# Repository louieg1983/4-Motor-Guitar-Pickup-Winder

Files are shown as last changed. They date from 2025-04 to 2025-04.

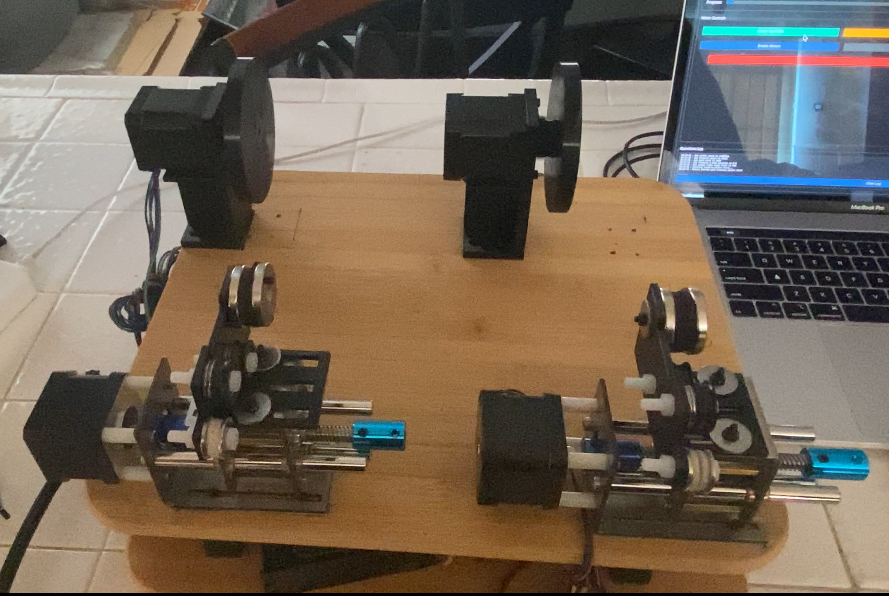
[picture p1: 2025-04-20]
Winder_Setup.jpg

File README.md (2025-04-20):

# 4-Motor-Guitar-Pickup-Winder

This project uses 4 stepper motors to wind guitar pickups. 

How it works:

There are two motors that will turn the bobbins and there are two motors that serve as traverse motors. The code has Winder Motor 2 and Traverse Motor 2 mirror the main motors. You can edit the code to control the motors individually if you would like but my goal was to wind a set of humbuckers in one shot to save time and resources. 

All motors are NEMA 17 stepper Motors. They are being driven by TB6600 Stepper Motor Drivers. The Winder Motors are set to 32 micro steps while the Traverse Motors are set to 16 micro steps. All are being powered by a 36V 10A Switch Power Supply. So far there have been no issues with this configuration. 

The TB6600 motors are then connected to the pins on the ESP32 board. You can use an Arduino board if you would like. You will just need to edit the code accroding to the pins that you are using. 

I built a wire feeder using Tinkercad. I can provide that STL file as well. You can also design your own if you would like. So far, no issues at all. Though I would like to come up with a more elegant solution. At the moment, I am using two rollers, custom made tensioner (two metal washers with felt washers, nylon screws and nuts to hold everything to the wire feeder plate, and two Neodymium magnets with felt pads. The theory or thought process was to use the washers with felt to keep the wire from bouncing all over the place and have some tension and then have the magnets keep the constant tension as the wire is feed to the bobbin. 

Amazon links for the parts used:

4 - https://www.amazon.com/dp/B07PQ5KNKR?ref=ppx_yo2ov_dt_b_fed_asin_title

2 - https://www.amazon.com/dp/B09KRJDRVH?ref=ppx_yo2ov_dt_b_fed_asin_title

2- https://www.amazon.com/dp/B00PNEQKC0?ref=ppx_yo2ov_dt_b_fed_asin_title

1 - https://www.amazon.com/dp/B01EV70C78?ref=ppx_yo2ov_dt_b_fed_asin_title

1 - https://www.amazon.com/dp/B08H292YZV?ref=ppx_yo2ov_dt_b_fed_asin_title

1 - https://www.amazon.com/dp/B097R2JMJT?ref=ppx_yo2ov_dt_b_fed_asin_title&th=1

1- https://www.amazon.com/dp/B0CLK7J4NB?ref=ppx_yo2ov_dt_b_fed_asin_title&th=1

1- https://www.amazon.com/dp/B0B82BBKCY?ref=ppx_yo2ov_dt_b_fed_asin_title&th=1

1 - https://www.amazon.com/dp/B082TQ11P2?ref=ppx_yo2ov_dt_b_fed_asin_title&th=1

1 - https://www.amazon.com/dp/B01NBE2XIR?ref_=ppx_hzsearch_conn_dt_b_fed_asin_title_1

Total cost is below $200. Great deal considering CNC Guitar Pickup Winders are about 6 to 7 times more. I could be wrong, I no math goods. 

I used the videos as well as resrouces from other builders. I drew a lot of inspiration from all these resources. Lots of great stuff out there. Hopefully you find something that you click with and you can use this design to build your own design. If you do, please do me the honors and share your work of art with me. I would love to see if this helps!

Resources/Inspirations/3D Parts

https://github.com/sandy9159/DIY-Arduino-based-Guitar-Pickup-Coil-Winder

https://github.com/fps/OPWF

https://github.com/speccyfan/wm/blob/master/wm1.1/stl/bracket-right.stl

https://www.youtube.com/watch?v=pJiwjPVOXLA

https://www.youtube.com/watch?v=IrS8BBjuDdw

https://www.youtube.com/watch?v=xya4ipu7bTk

https://www.youtube.com/watch?v=YcfYJsYc00k

https://www.youtube.com/watch?v=phCA-h2uJGQ&t=526s

https://www.youtube.com/shorts/mcej-a_-2Q8

https://www.youtube.com/watch?v=2DeUdFgyJEU

https://www.youtube.com/watch?v=DuSMk63nonc&t=84s

Also, if you do not have a 3D printer you may want to invest in a cheap one just to print out the parts otherwise you will need to buy something comparable or you can enlist the services of someone with a 3D printer. 

I hope this helps! And HAVE FUN!

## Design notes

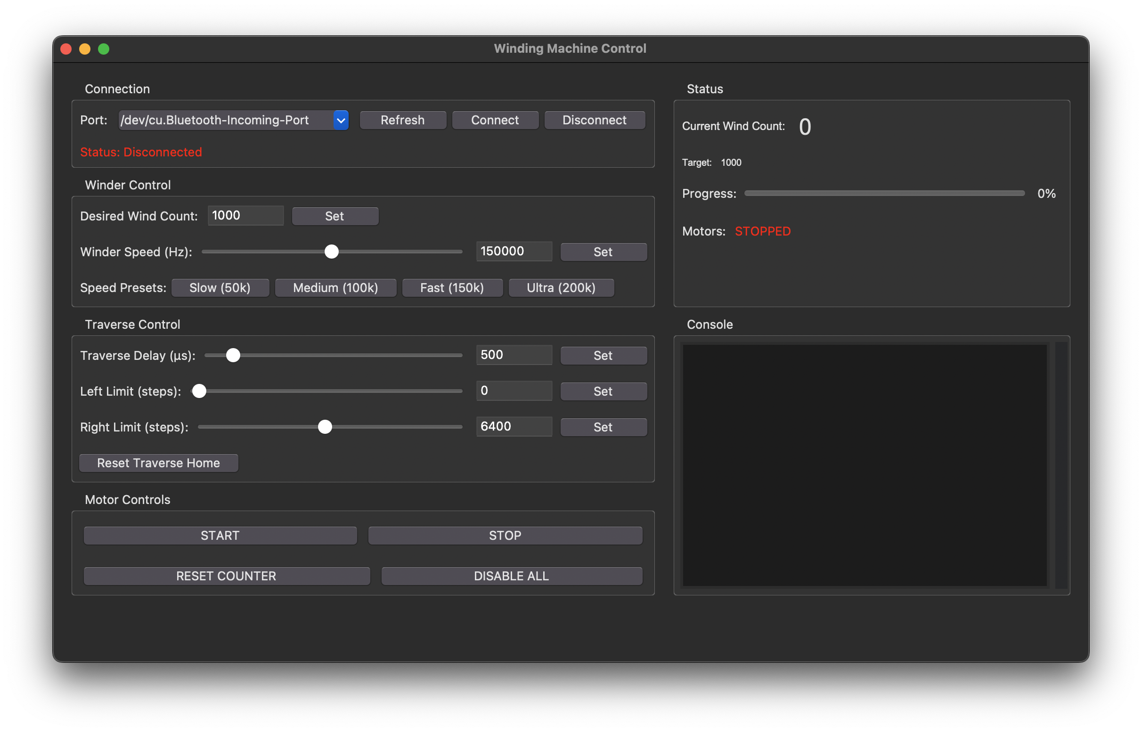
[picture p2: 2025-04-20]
Python_GUI.png

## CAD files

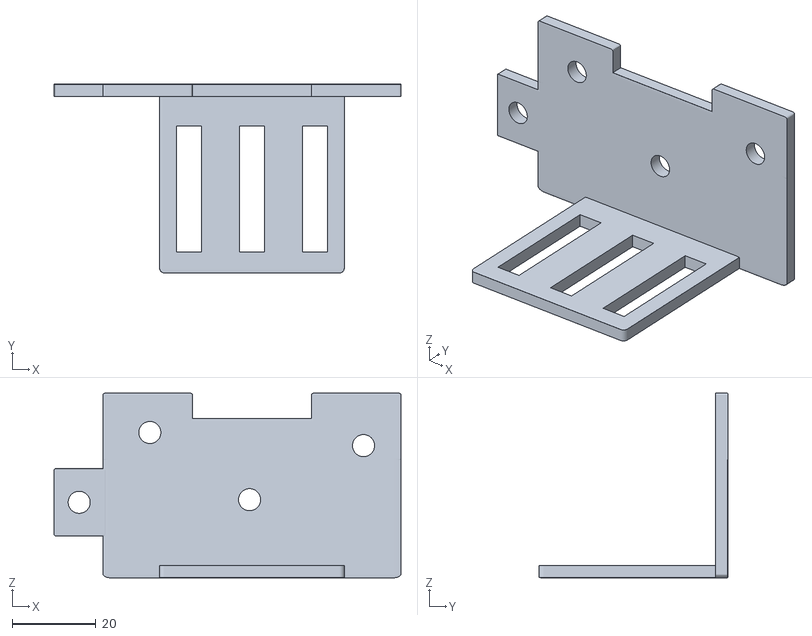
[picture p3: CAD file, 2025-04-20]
WIRE_FEEDER_TRAVERSE_PLATE.stl
82.7 x 45.0 x 44.0

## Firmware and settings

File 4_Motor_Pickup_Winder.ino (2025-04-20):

#include <FastAccelStepper.h>

//-------------------- Pin Definitions --------------------
// Winder Motor Pins
#define WINDER_DIR_PIN      26    // Direction pin for Winder Motor
#define WINDER_STEP_PIN     27    // Step pulse pin for Winder Motor
#define WINDER_ENABLE_PIN   32    // Enable pin for Winder Motor (LOW enables)

// Traverse Motor Pins
#define TRAVERSE_DIR_PIN    13    // Direction pin for Traverse Motor
#define TRAVERSE_STEP_PIN   12    // Step pulse pin for Traverse Motor
#define TRAVERSE_ENABLE_PIN 33    // Enable pin for Traverse Motor (LOW enables)

// Hall Sensor Pin
#define HALL_SENSOR_PIN     34

// Additional Winder Motor Pins
#define WINDER2_DIR_PIN     25    // Direction pin for 2nd Winder Motor
#define WINDER2_STEP_PIN    14    // Step pulse pin for 2nd Winder Motor
#define WINDER2_ENABLE_PIN  23    // Enable pin for 2nd Winder Motor (LOW enables)

// Additional Traverse Motor Pins
#define TRAVERSE2_DIR_PIN   4     // Direction pin for Traverse Motor 2
#define TRAVERSE2_STEP_PIN  2     // Step pulse pin for Traverse Motor 2
#define TRAVERSE2_ENABLE_PIN 15   // Enable pin for Traverse Motor 2 (LOW enables)

//-------------------- Global Objects --------------------
FastAccelStepperEngine engine = FastAccelStepperEngine();
FastAccelStepper *winderStepper = NULL;
FastAccelStepper *winder2Stepper = NULL;
FastAccelStepper *traverseStepper = NULL;
FastAccelStepper *traverse2Stepper = NULL;

//-------------------- Global Variables --------------------
// Control flags
bool motorsRunning = false;  

// Winder Motor Variables
volatile long windCount = 0;      // Incremented via ISR on hall sensor
int desiredWindCount = 1000;      // Target wind count
long winderSpeed = 150000;        // Default winder speed (Hz)
long winderAcceleration = 20000;  // Winder acceleration
const int slowdownWinds = 111;    // Slowdown threshold

// Traverse Motor Variables
const int STEPS_PER_REVOLUTION = 3200;  // 3200 microsteps per revolution
int traverseStepDelay = 500;      // Delay per half-step (µs)
int leftSweepLimit = 0;           // Left sweep limit in steps
int rightSweepLimit = 6400;       // Right sweep limit in steps
bool traverseMovingRight = true;  // Traverse direction flag
int currentTraverseStep = 0;      // Current traverse position in steps
int currentTraverse2Step = 0;     // Current traverse2 position in steps

//-------------------- Status Timer Variables --------------------
unsigned long lastStatusPrintTime = 0;
const unsigned long statusPrintInterval = 1000; // 1 second

//-------------------- Function Prototypes --------------------
void processCommand(String command);
void updateWinderSpeed();
void moveTraverseToPosition(int targetSteps);
void moveTraverse2ToPosition(int targetSteps);
void startMotors();
void stopMotors();
void countWinds();
void pulseTraverseStep(int pin, int delay_us);
void controlBothTraverseMotors(int stepDelay, int leftLimit, int rightLimit);
void disableAllMotors();

//-------------------- Helper Function for Step Pulses --------------------
void pulseTraverseStep(int pin, int delay_us) {
  digitalWrite(pin, HIGH);
  delayMicroseconds(10); // Ensure minimum pulse width
  digitalWrite(pin, LOW);
  delayMicroseconds(delay_us - 10 > 0 ? delay_us - 10 : 1); // Maintain timing
}

//-------------------- Control Both Traverse Motors --------------------
void controlBothTraverseMotors(int stepDelay, int leftLimit, int rightLimit) {
  if (traverseMovingRight) {
    // Both motors moving right (increasing position)
    if (currentTraverseStep >= rightLimit) {
      // Reached right limit, change direction for both motors
      traverseMovingRight = false;
      Serial.println("Traverse: Changing direction to LEFT");
    } else {
      // Continue moving right for both motors
      // Traverse 1
      digitalWrite(TRAVERSE_DIR_PIN, HIGH); // Direction for RIGHT movement
      pulseTraverseStep(TRAVERSE_STEP_PIN, stepDelay);
      currentTraverseStep++; // Update position
      
      // Traverse 2 - SAME direction
      digitalWrite(TRAVERSE2_DIR_PIN, HIGH); // Direction for RIGHT movement
      pulseTraverseStep(TRAVERSE2_STEP_PIN, stepDelay);
      currentTraverse2Step++; // Update position
    }
  } else {
    // Both motors moving left (decreasing position)
    if (currentTraverseStep <= leftLimit) {
      // Reached left limit, change direction for both motors
      traverseMovingRight = true;
      Serial.println("Traverse: Changing direction to RIGHT");
    } else {
      // Continue moving left for both motors
      // Traverse 1
      digitalWrite(TRAVERSE_DIR_PIN, LOW); // Direction for LEFT movement
      pulseTraverseStep(TRAVERSE_STEP_PIN, stepDelay);
      currentTraverseStep--; // Update position
      
      // Traverse 2 - SAME direction
      digitalWrite(TRAVERSE2_DIR_PIN, LOW); // Direction for LEFT movement
      pulseTraverseStep(TRAVERSE2_STEP_PIN, stepDelay);
      currentTraverse2Step--; // Update position
    }
  }
}

//-------------------- Process Serial Commands --------------------
void processCommand(String command) {
  if (command == "S") {
    startMotors();
  }
  else if (command == "T") {
    stopMotors();
  }
  else if (command == "R") {
    windCount = 0;
    Serial.println("Wind count reset to 0.");
    Serial.print("Current wind count: ");
    Serial.println(windCount);
  
    // Monitor the Hall sensor status
    Serial.print("Hall sensor current state: ");
    Serial.println(digitalRead(HALL_SENSOR_PIN) == HIGH ? "HIGH" : "LOW");
  }
  else if (command.startsWith("N")) {
    int newWindCount = command.substring(1).toInt();
    if (newWindCount > 0) {
      desiredWindCount = newWindCount;
      Serial.print("Desired wind count set to ");
      Serial.println(desiredWindCount);
    }
  }
  else if (command.startsWith("w_speed:")) {
    long newSpeed = command.substring(8).toInt();
    if (newSpeed > 0) {
      winderSpeed = newSpeed;
      if (winderStepper && motorsRunning) {
        winderStepper->setSpeedInHz(winderSpeed);
      }
      if (winder2Stepper && motorsRunning) {
        winder2Stepper->setSpeedInHz(winderSpeed);
      }
      Serial.print("Winder speed set to ");
      Serial.print(winderSpeed);
      Serial.println(" Hz");
    }
  }
  else if (command.startsWith("t_speed:")) {
    int newDelay = command.substring(8).toInt();
    if (newDelay > 0) {
      traverseStepDelay = newDelay;
      Serial.print("Traverse step delay set to ");
      Serial.print(traverseStepDelay);
      Serial.println(" microseconds");
    }
  }
  else if (command.startsWith("t_leftlimit:")) {
    int newLimit = command.substring(12).toInt();
    leftSweepLimit = newLimit;
    Serial.print("Left sweep limit set to ");
    Serial.println(leftSweepLimit);
  }
  else if (command.startsWith("t_rightlimit:")) {
    int newLimit = command.substring(13).toInt();
    if (newLimit >= 0 && newLimit <= 12800) {  // Allow up to 4 full revolutions
      rightSweepLimit = newLimit;
      Serial.print("Right sweep limit set to: ");
      Serial.println(rightSweepLimit);
    } else {
      Serial.println("Error: Right limit must be between 0 and 12800");
    }
  }
  else if (command == "t_home") {
    currentTraverseStep = 0;
    Serial.println("Traverse position reset to home (0)");
  }
  else if (command == "disable_all_motors") {
    disableAllMotors();
  }
  else {
    Serial.print("Unknown command: ");
    Serial.println(command);
  }
}

//-------------------- Start Motors Function --------------------
void startMotors() {
  if (!motorsRunning) {
    // Enable traverse motors first
    digitalWrite(TRAVERSE_ENABLE_PIN, LOW);
    digitalWrite(TRAVERSE2_ENABLE_PIN, LOW);
    
    // Initialize traverse direction flags
    traverseMovingRight = true;
    
    // Send a burst of steps to get the traverse motors moving
    Serial.println("Starting traverse motors first...");
    for (int i = 0; i < 50; i++) {
      digitalWrite(TRAVERSE_DIR_PIN, HIGH);
      digitalWrite(TRAVERSE2_DIR_PIN, HIGH);
      
      pulseTraverseStep(TRAVERSE_STEP_PIN, 300); 
      pulseTraverseStep(TRAVERSE2_STEP_PIN, 300);
      delay(5);
    }
    
    // Add a delay before starting winder motors
    delay(1000);
    
    Serial.println("Traverse motors running, now starting winder motors...");
    
    // Initialize the winder motors
    if (winderStepper) {
      winderStepper->stopMove();
      winderStepper->forceStopAndNewPosition(0);
    }
    
    if (winder2Stepper) {
      winder2Stepper->stopMove();
      winder2Stepper->forceStopAndNewPosition(0);
    }
    
    // Enable Winder Motors
    digitalWrite(WINDER_ENABLE_PIN, LOW);
    digitalWrite(WINDER2_ENABLE_PIN, LOW);
    
    // Configure and start the Winder Motors rotation
    if (winderStepper) {
      winderStepper->setSpeedInHz(winderSpeed);
      winderStepper->setAcceleration(winderAcceleration);
      winderStepper->runForward();
    }
    
    if (winder2Stepper) {
      winder2Stepper->setSpeedInHz(winderSpeed);
      winder2Stepper->setAcceleration(winderAcceleration);
      winder2Stepper->runForward();
    }
    
    // Set flag
    motorsRunning = true;
    
    Serial.println("All motors running");
  }
}

//-------------------- Disable All Motors Function --------------------
void disableAllMotors() {
  // First stop any stepper movement
  if (winderStepper) {
    winderStepper->stopMove();
    winderStepper->forceStopAndNewPosition(0);
    winderStepper->disableOutputs();
  }
  if (winder2Stepper) {
    winder2Stepper->stopMove();
    winder2Stepper->forceStopAndNewPosition(0);
    winder2Stepper->disableOutputs();
  }
  
  // Disable all motor outputs
  digitalWrite(WINDER_ENABLE_PIN, HIGH);
  digitalWrite(WINDER2_ENABLE_PIN, HIGH);
  digitalWrite(TRAVERSE_ENABLE_PIN, HIGH);
  digitalWrite(TRAVERSE2_ENABLE_PIN, HIGH);
  
  // Update state flag
  motorsRunning = false;
  
  Serial.println("All motors disabled.");
}

//-------------------- Stop Motors Function --------------------
void stopMotors() {
  if (motorsRunning) {
    // Stop the winder stepper motors
    if (winderStepper) {
      winderStepper->stopMove();
      winderStepper->forceStopAndNewPosition(0);
    }
    if (winder2Stepper) {
      winder2Stepper->stopMove();
      winder2Stepper->forceStopAndNewPosition(0);
    }
    
    // Disable all motors
    digitalWrite(WINDER_ENABLE_PIN, HIGH);
    digitalWrite(WINDER2_ENABLE_PIN, HIGH);
    digitalWrite(TRAVERSE_ENABLE_PIN, HIGH);
    digitalWrite(TRAVERSE2_ENABLE_PIN, HIGH);
    
    // Update motor running flag
    motorsRunning = false;
    
    Serial.println("All motors stopped and disabled.");
  }
}

//-------------------- Update Winder Speed --------------------
void updateWinderSpeed() {
  if (!motorsRunning) return;
  
  int remainingWinds = desiredWindCount - windCount;
  if (remainingWinds <= slowdownWinds) {
    float ratio = remainingWinds / (float)slowdownWinds;
    float slowdownFactor = (ratio > 0.1f) ? ratio : 0.1f;
    long adjustedSpeed = winderSpeed * slowdownFactor;
    if (winderStepper) {
      winderStepper->setSpeedInHz(adjustedSpeed);
    }
    if (winder2Stepper) {
      winder2Stepper->setSpeedInHz(adjustedSpeed);
    }
  }
}

//-------------------- Move Traverse Function (Motor 1) --------------------
void moveTraverseToPosition(int targetSteps) {
  // Force enable the traverse motor
  digitalWrite(TRAVERSE_ENABLE_PIN, LOW);
  
  if (targetSteps > currentTraverseStep) {
    while (currentTraverseStep < targetSteps) {
      digitalWrite(TRAVERSE_DIR_PIN, HIGH);
      pulseTraverseStep(TRAVERSE_STEP_PIN, traverseStepDelay);
      currentTraverseStep++;
    }
  }
  else if (targetSteps < currentTraverseStep) {
    while (currentTraverseStep > targetSteps) {
      digitalWrite(TRAVERSE_DIR_PIN, LOW);
      pulseTraverseStep(TRAVERSE_STEP_PIN, traverseStepDelay);
      currentTraverseStep--;
    }
  }
}

//-------------------- Move Traverse Function (Motor 2) --------------------
void moveTraverse2ToPosition(int targetSteps) {
  // Force enable the traverse motor
  digitalWrite(TRAVERSE2_ENABLE_PIN, LOW);
  
  if (targetSteps > currentTraverse2Step) {
    while (currentTraverse2Step < targetSteps) {
      digitalWrite(TRAVERSE2_DIR_PIN, HIGH);
      pulseTraverseStep(TRAVERSE2_STEP_PIN, traverseStepDelay);
      currentTraverse2Step++;
    }
  }
  else if (targetSteps < currentTraverse2Step) {
    while (currentTraverse2Step > targetSteps) {
      digitalWrite(TRAVERSE2_DIR_PIN, LOW);
      pulseTraverseStep(TRAVERSE2_STEP_PIN, traverseStepDelay);
      currentTraverse2Step--;
    }
  }
}

//-------------------- Wind Counting Function --------------------
void countWinds() {
  static int lastSensorState = HIGH;
  int sensorState = digitalRead(HALL_SENSOR_PIN);
  
  // Detect falling edge (magnet approaching sensor)
  if (lastSensorState == HIGH && sensorState == LOW) {
    windCount++;
    
    // Output wind count periodically for debugging
    if (windCount % 5 == 0 || windCount < 10) {
      Serial.print("Wind Count: ");
      Serial.println(windCount);
    }
  }
  
  lastSensorState = sensorState;
}

//-------------------- Setup --------------------
void setup() {
  Serial.begin(115200);
  
  // Initialize the FastAccelStepper engine
  engine.init();

  // Reset the wind count
  windCount = 0;
  
  // Configure Winder Motors
  pinMode(WINDER_DIR_PIN, OUTPUT);
  pinMode(WINDER_STEP_PIN, OUTPUT);
  pinMode(WINDER_ENABLE_PIN, OUTPUT);
  digitalWrite(WINDER_ENABLE_PIN, HIGH);  // Start disabled
  
  pinMode(WINDER2_DIR_PIN, OUTPUT);
  pinMode(WINDER2_STEP_PIN, OUTPUT);
  pinMode(WINDER2_ENABLE_PIN, OUTPUT);
  digitalWrite(WINDER2_ENABLE_PIN, HIGH);  // Start disabled
  
  // Configure Traverse Motors
  pinMode(TRAVERSE_DIR_PIN, OUTPUT);
  pinMode(TRAVERSE_STEP_PIN, OUTPUT);
  pinMode(TRAVERSE_ENABLE_PIN, OUTPUT);
  digitalWrite(TRAVERSE_ENABLE_PIN, HIGH); // Start disabled
  
  pinMode(TRAVERSE2_DIR_PIN, OUTPUT);
  pinMode(TRAVERSE2_STEP_PIN, OUTPUT);
  pinMode(TRAVERSE2_ENABLE_PIN, OUTPUT);
  digitalWrite(TRAVERSE2_ENABLE_PIN, HIGH); // Start disabled
  
  // Configure Hall Sensor
  pinMode(HALL_SENSOR_PIN, INPUT_PULLUP);
  
  // Setup steppers
  winderStepper = engine.stepperConnectToPin(WINDER_STEP_PIN);
  if (winderStepper) {
    winderStepper->setDirectionPin(WINDER_DIR_PIN);
    winderStepper->setEnablePin(WINDER_ENABLE_PIN);
    winderStepper->setAutoEnable(false);
    winderStepper->setSpeedInHz(winderSpeed);
    winderStepper->setAcceleration(winderAcceleration);
  }
  
  winder2Stepper = engine.stepperConnectToPin(WINDER2_STEP_PIN);
  if (winder2Stepper) {
    winder2Stepper->setDirectionPin(WINDER2_DIR_PIN);
    winder2Stepper->setEnablePin(WINDER2_ENABLE_PIN);
    winder2Stepper->setAutoEnable(false);
    winder2Stepper->setSpeedInHz(winderSpeed);
    winder2Stepper->setAcceleration(winderAcceleration);
  }
  
  traverseStepper = engine.stepperConnectToPin(TRAVERSE_STEP_PIN);
  if (traverseStepper) {
    traverseStepper->setDirectionPin(TRAVERSE_DIR_PIN);
    traverseStepper->setEnablePin(TRAVERSE_ENABLE_PIN);
    traverseStepper->setAutoEnable(false);
    traverseStepper->setSpeedInHz(4000);
  }
  
  traverse2Stepper = engine.stepperConnectToPin(TRAVERSE2_STEP_PIN);
  if (traverse2Stepper) {
    traverse2Stepper->setDirectionPin(TRAVERSE2_DIR_PIN);
    traverse2Stepper->setEnablePin(TRAVERSE2_ENABLE_PIN);
    traverse2Stepper->setAutoEnable(false);
    traverse2Stepper->setSpeedInHz(4000);
  }
  
  delay(1000);
  Serial.println("System initialized");
  Serial.println("Available commands:");
  Serial.println("  S             -> Start motors");
  Serial.println("  T             -> Stop motors");
  Serial.println("  R             -> Reset wind count");
  Serial.println("  N<number>     -> Set desired wind count");
  Serial.println("  w_speed:<Hz>  -> Set winder speed in Hz");
  Serial.println("  t_speed:<us>  -> Set traverse step delay (µs)");
  Serial.println("  t_leftlimit:X -> Set left sweep limit (steps)");
  Serial.println("  t_rightlimit:X -> Set right sweep limit (steps)");
  Serial.println("  t_home        -> Reset traverse position to 0 (home)");
  Serial.println("  disable_all_motors -> Disable all motors");
}

//-------------------- Main Loop --------------------
void loop() {
  // Process incoming serial commands
  if (Serial.available() > 0) {
    String command = Serial.readStringUntil('\n');
    command.trim();
    processCommand(command);
  }
  
  // This section runs when motors are actively running
  if (motorsRunning) {
    // Update winder motor speed if needed
    updateWinderSpeed();
    
    // Process only a few steps per loop iteration
    for (int i = 0; i < 5; i++) {
      // Enable traverse motors
      digitalWrite(TRAVERSE_ENABLE_PIN, LOW);
      digitalWrite(TRAVERSE2_ENABLE_PIN, LOW);
      
      // Use the synchronized control function for both traverse motors
      controlBothTraverseMotors(traverseStepDelay, leftSweepLimit, rightSweepLimit);
      
      // Short delay to prevent overwhelming the CPU
      delayMicroseconds(100);
    }
    
    // Count winds via hall sensor
    countWinds();
    
    // Check if we've reached the desired wind count
    if (desiredWindCount > 0 && (windCount + windCountOffset) >= desiredWindCount) {
      stopMotors();
      Serial.print("Target wind count reached: ");
      Serial.println(windCount + windCountOffset);
    }
  }
  
  // Print status every second
  if (millis() - lastStatusPrintTime >= statusPrintInterval) {
    Serial.print("Current Wind Count: ");
    Serial.println(windCount);
    lastStatusPrintTime = millis();
  }
}

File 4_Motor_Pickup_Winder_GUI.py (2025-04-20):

import tkinter as tk
from tkinter import ttk, messagebox
import serial
import serial.tools.list_ports
import threading
import time

class WinderControlApp:
    def __init__(self, root):
        self.root = root
        self.root.title("Winding Machine Control")
        self.root.geometry("750x550")
        self.root.configure(padx=10, pady=10)
        
        # Serial connection variables
        self.serial_conn = None
        self.connected = False
        self.monitoring_thread = None
        self.thread_running = False
        
        # Winding machine variables
        self.current_wind_count = 0
        self.desired_wind_count = 1000
        self.winder_speed = 150000
        self.traverse_delay = 500
        self.left_limit = 0
        self.right_limit = 6400
        
        # UI layout
        self.create_interface()
        
        # Update status periodically
        self.root.after(100, self.update_status)
    
    def create_interface(self):
        # Set up grid for two-column layout
        self.root.grid_columnconfigure(0, weight=1)
        self.root.grid_columnconfigure(1, weight=1)
        
        # Create main frames
        left_frame = ttk.Frame(self.root)
        left_frame.grid(row=0, column=0, sticky="nsew", padx=5, pady=5)
        
        right_frame = ttk.Frame(self.root)
        right_frame.grid(row=0, column=1, sticky="nsew", padx=5, pady=5)
        
        # Create connection section
        self.create_connection_section(left_frame)
        
        # Create winder control section
        self.create_winder_control_section(left_frame)
        
        # Create traverse control section
        self.create_traverse_control_section(left_frame)
        
        # Create motor buttons section
        self.create_motor_buttons_section(left_frame)
        
        # Create status display section
        self.create_status_section(right_frame)
        
        # Create console section
        self.create_console_section(right_frame)
    
    def create_connection_section(self, parent):
        connection_frame = ttk.LabelFrame(parent, text="Connection")
        connection_frame.pack(fill="x", padx=5, pady=5)
        
        # Port selection row
        port_frame = ttk.Frame(connection_frame)
        port_frame.pack(fill="x", padx=5, pady=5)
        
        ttk.Label(port_frame, text="Port:").pack(side="left")
        
        # Get available ports
        self.port_var = tk.StringVar()
        self.port_combo = ttk.Combobox(port_frame, textvariable=self.port_var)
        self.port_combo.pack(side="left", padx=5, expand=True, fill="x")
        self.refresh_ports()
        
        ttk.Button(port_frame, text="Refresh", command=self.refresh_ports).pack(side="left", padx=2)
        ttk.Button(port_frame, text="Connect", command=self.connect_serial).pack(side="left", padx=2)
        ttk.Button(port_frame, text="Disconnect", command=self.disconnect_serial).pack(side="left", padx=2)
        
        # Status indicator
        status_frame = ttk.Frame(connection_frame)
        status_frame.pack(fill="x", padx=5, pady=5)
        
        self.connection_status = ttk.Label(status_frame, text="Status: Disconnected", foreground="red")
        self.connection_status.pack(side="left")
    
    def create_winder_control_section(self, parent):
        winder_frame = ttk.LabelFrame(parent, text="Winder Control")
        winder_frame.pack(fill="x", padx=5, pady=5)
        
        # Wind count row
        wind_count_frame = ttk.Frame(winder_frame)
        wind_count_frame.pack(fill="x", padx=5, pady=5)
        
        ttk.Label(wind_count_frame, text="Desired Wind Count:").pack(side="left")
        self.wind_count_var = tk.StringVar(value=str(self.desired_wind_count))
        wind_count_entry = ttk.Entry(wind_count_frame, textvariable=self.wind_count_var, width=8)
        wind_count_entry.pack(side="left", padx=5)
        ttk.Button(wind_count_frame, text="Set", command=self.set_wind_count).pack(side="left")
        
        # Winder speed row
        speed_frame = ttk.Frame(winder_frame)
        speed_frame.pack(fill="x", padx=5, pady=5)
        
        ttk.Label(speed_frame, text="Winder Speed (Hz):").pack(side="left")
        self.winder_speed_var = tk.StringVar(value=str(self.winder_speed))
        
        self.winder_speed_slider = ttk.Scale(speed_frame, from_=1000, to=300000, orient="horizontal", 
                                           command=self.update_winder_speed_display)
        self.winder_speed_slider.set(self.winder_speed)
        self.winder_speed_slider.pack(side="left", padx=5, expand=True, fill="x")
        
        winder_speed_entry = ttk.Entry(speed_frame, textvariable=self.winder_speed_var, width=8)
        winder_speed_entry.pack(side="left", padx=5)
        ttk.Button(speed_frame, text="Set", command=self.set_winder_speed).pack(side="left")
        
        # Create a row of preset speed buttons
        preset_frame = ttk.Frame(winder_frame)
        preset_frame.pack(fill="x", padx=5, pady=5)
        
        ttk.Label(preset_frame, text="Speed Presets:").pack(side="left")
        ttk.Button(preset_frame, text="Slow (50k)", command=lambda: self.set_preset_speed(50000)).pack(side="left", padx=2)
        ttk.Button(preset_frame, text="Medium (100k)", command=lambda: self.set_preset_speed(100000)).pack(side="left", padx=2)
        ttk.Button(preset_frame, text="Fast (150k)", command=lambda: self.set_preset_speed(150000)).pack(side="left", padx=2)
        ttk.Button(preset_frame, text="Ultra (200k)", command=lambda: self.set_preset_speed(200000)).pack(side="left", padx=2)
    
    def create_traverse_control_section(self, parent):
        traverse_frame = ttk.LabelFrame(parent, text="Traverse Control")
        traverse_frame.pack(fill="x", padx=5, pady=5)
        
        # Traverse speed row
        speed_frame = ttk.Frame(traverse_frame)
        speed_frame.pack(fill="x", padx=5, pady=5)
        
        ttk.Label(speed_frame, text="Traverse Delay (µs):").pack(side="left")
        self.traverse_delay_var = tk.StringVar(value=str(self.traverse_delay))
        
        self.traverse_delay_slider = ttk.Scale(speed_frame, from_=100, to=5000, orient="horizontal", 
                                             command=self.update_traverse_delay_display)
        self.traverse_delay_slider.set(self.traverse_delay)
        self.traverse_delay_slider.pack(side="left", padx=5, expand=True, fill="x")
        
        traverse_delay_entry = ttk.Entry(speed_frame, textvariable=self.traverse_delay_var, width=8)
        traverse_delay_entry.pack(side="left", padx=5)
        ttk.Button(speed_frame, text="Set", command=self.set_traverse_delay).pack(side="left")
        
        # Left limit row
        left_limit_frame = ttk.Frame(traverse_frame)
        left_limit_frame.pack(fill="x", padx=5, pady=5)
        
        ttk.Label(left_limit_frame, text="Left Limit (steps):").pack(side="left")
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

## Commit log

2025-04-20 Create 4_Motor_Pickup_Winder.ino
    Arduino code for pickup winder. This was being used with an ESP32 board. This should also work with Arduino Uno boards as well. You will just need to change the pins on the code based on your based.
2025-04-20 Create 4_Motor_Pickup_Winder_GUI.py
    This is a simple Python GUI to control the motor. You can use this as a base. You can add more functions as needed.
2025-04-20 Python GUI
    Simply Python GUI to control the motors.
2025-04-20 Python GUI
    Simple Python GUI to control the motors.
2025-04-20 Wire Feeder Traverse Plate I created in Tinkercad.
    [WIRE_FEEDER_TRAVERSE_PLATE.stl]
